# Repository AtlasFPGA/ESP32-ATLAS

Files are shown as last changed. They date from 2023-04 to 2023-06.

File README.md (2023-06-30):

# ESP32-ATLAS
   Diseño en desarrollo para el ESP32 DEV KIT V1 usado de forma básica con sus  25 señales,se necesita disponer de un VGA64.
   No podíamos dejar pasar la oportunidad de alojar el ESP32 en el interior de la I/O BOARD ATLAS,este microcontroladro lleva muchos años en el mercado,tant es así que el ESP32 sigue siendo un producto puntero.
   Es importantísimo tener su Software en ATLAS, y con la tercera iteración de correspondencia de pines cubre toda la placa I/O BOARD ATLAS.
   La inicialización de FABGL con su configuración en la mayoría de las placas es la siguiente.
inicialización VGA FABGL:

   Vídeo que muestra, el correcto funcionamiento del recolocador que nos permitirá jugar con audio amplificado, i2s así como i2c en el futuro.

---

## Correcto funcionamiento recolocador ESP32:

Correcto funcionamiento del recolocador ESP32 (https://youtu.be/WPQtUhWn7BE)

---

VGAController.begin(GPIO_NUM_22, GPIO_NUM_21, GPIO_NUM_19, GPIO_NUM_18, GPIO_NUM_5, GPIO_NUM_4, GPIO_NUM_23, GPIO_NUM_15);

Leyendo el quema vemos que significado tiene de señales con sus nombres lógicos de los bits de color así como la frecuencia horizontal y vertical.

VGAController.begin(RED_1, RED_0 , GREEN_1, GREEN_0, BLUE_1, BLUE_0, H_SYNC, V_SYNC)

Inicialización ESP32 en ATLAS con el recolocador creado:

## VGAController.begin(GPIO_NUM_32, GPIO_NUM_33, GPIO_NUM_27, GPIO_NUM_4, GPIO_NUM_17, GPIO_NUM_13, GPIO_NUM_16, GPIO_NUM_15);

El recolocador de ATLAS tiene una colocación diferente.
---

Colocación del ESP32 en la placa I/O Board ATLAS Morada:
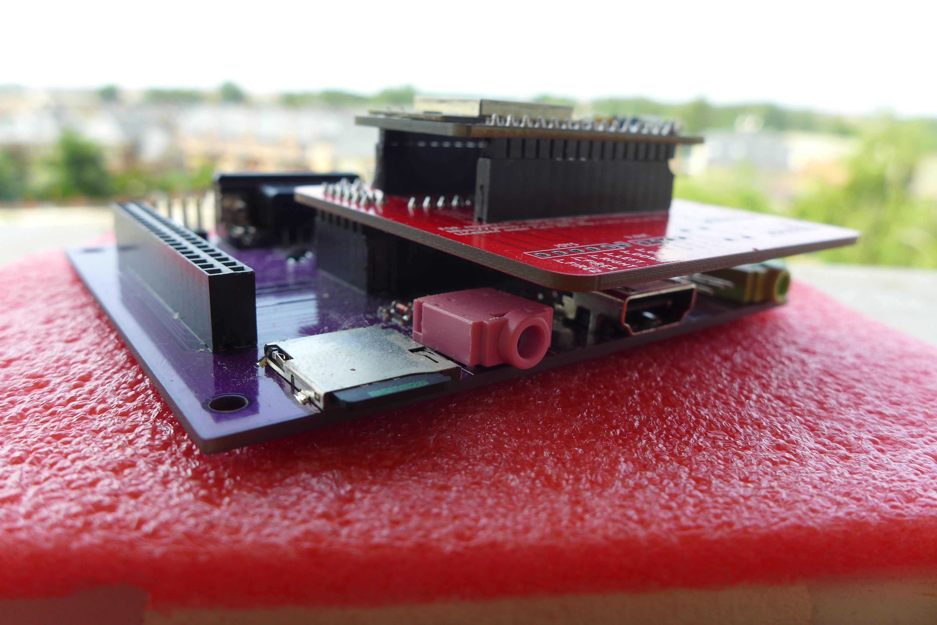
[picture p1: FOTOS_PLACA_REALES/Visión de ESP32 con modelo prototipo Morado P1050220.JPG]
Colocación del ESP32 en la placa I/O Board ATLAS Morada


---

Placa "La Roja" vista con el recolocador ESP32 desde el bus del sbc:
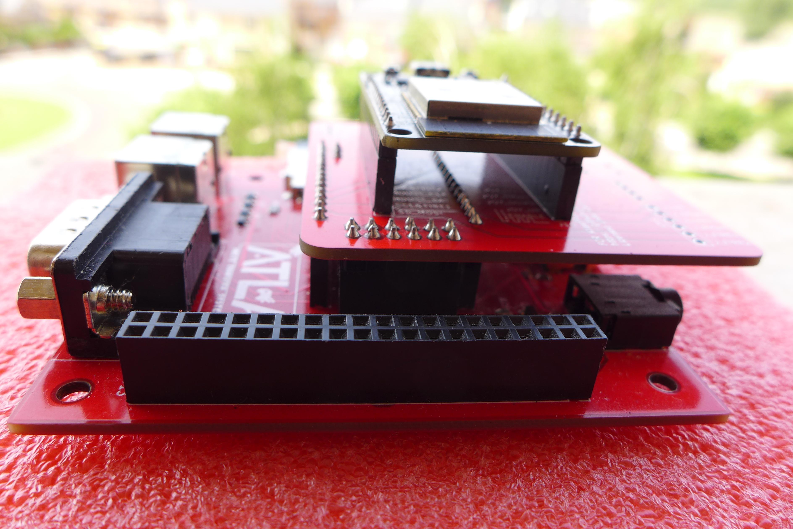
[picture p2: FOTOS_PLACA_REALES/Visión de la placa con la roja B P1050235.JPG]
Placa "La Roja" vista con el recolocador ESP32 desde el bus del sbc


---

Ensamblado ESP32 visto desde los puertos ps2 y db9 norma atari:
Ensamblado ESP32 visto desde los puertos ps2 y db9 norma atari

---

Visión de la placa recolocadora ESP32 superior:
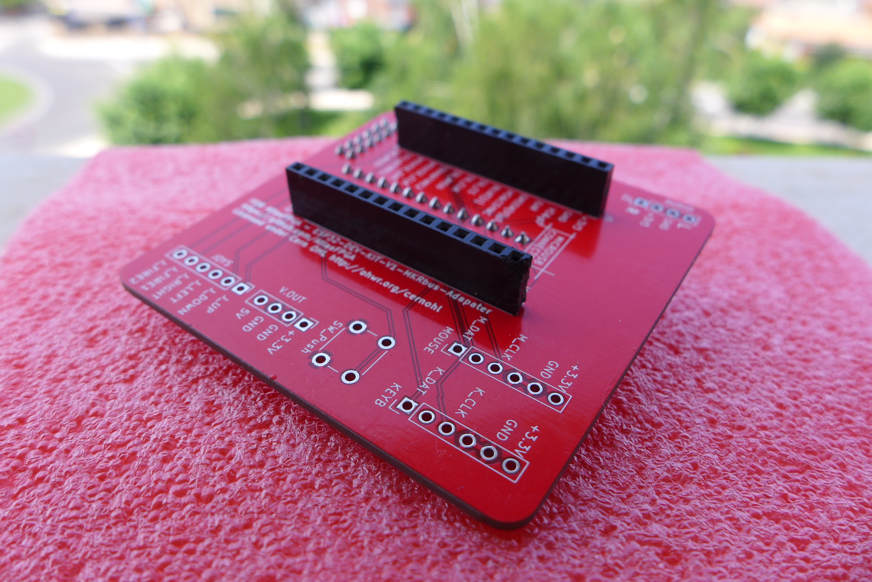
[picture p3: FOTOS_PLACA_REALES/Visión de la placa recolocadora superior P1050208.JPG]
Visión de la placa recolocadora superior


---
Visión de la placa recolocadora ESP32 infernior:
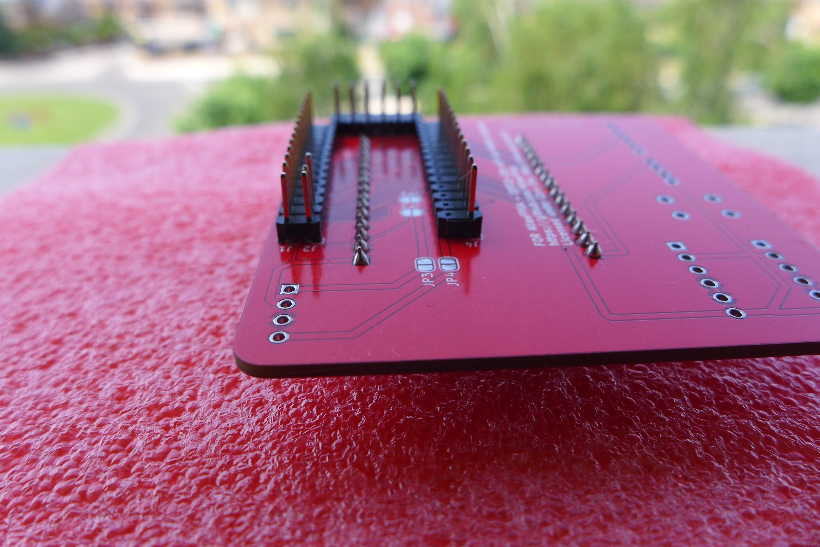
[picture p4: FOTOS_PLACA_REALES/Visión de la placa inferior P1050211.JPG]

   
---   

# Versión final sin amplificación de sonido:

Ver vídeo diseño recolocador (https://www.youtube.com/watch?v=FslLuDT2TB8)

---   

# Vídeo del proceso de desarrollo del recolocador para ESP32 DEV KIT V1; así como mostrar el funcionamiento del VGA64 222+HS+VS de la placa I/O Board ATLAS:

Ver vídeo primera iteracion bitluni (https://www.youtube.com/watch?v=wdI3RePPbeQ)
  
---

señales ATLAS| aclaración en ESP32 DEV KIT 1 | numero pines
| :--- | ---: | :---:
Señal VGA64 | Casi todos los cores de ESP32 usan 64colores esquema 222+HS+VS | 8
Señal JOYSTICK DB9 | En preparación ATARI-PADDLE-ATLAS  | 6
Señal SD SPI | las señales QPI se usan en modo SPI| 4
Señal PS2 TECLADO  | Protocolo PS/2 | 2
Señal PS2 RATÓN | Protocolo PS/2 | 2
Señal Sonido Estereo | sonido delta sigma_(12bits) o un pwm_(10bits), DAC_ESP32(8bits)| 2
Señal Transmisión y Recepcion | RX TX sin gestión de flujo| 2
Señal EAR | Señal de entrada | 1

   No hay lugar para Las Señales de RX y TX como GPIOS, se tendrá que acceder desde el USB.
   En este diseño son Necesarias 27 señales, pero el ESP32 DEV KIT V1 dispone de 25 patillas/señales de las cuales 4 son de entrada, ahí conectamos las direcciones del mando de juegos de norma ATARI en el bus DB9.

   Inicialmente antes de realizar el recolocador final,hemos usado el esquema de bitluni:
   
   http://www.fabglib.org/conf_v_g_a.html
   
   Con la siguiente disposición de pines para la primera iteración de pines:
   
   VGAController.begin(GPIO_NUM_22, GPIO_NUM_21, GPIO_NUM_19, GPIO_NUM_18, GPIO_NUM_5, GPIO_NUM_4, GPIO_NUM_23, GPIO_NUM_15);
   
PINEADO


##   Nota importante fijarse en los 4 pines que sólo permiten señales de entrada corresponden a los GPIO36, GPIO39, GPIO34, y GPIO35.

---

# ASIGNACIÓN ACTUAL; buscando tener el I2C con pull up en el DB9 y los 2 DAC de 8bits de resolución en la salida de sonido:
   los GPIO asociados a la salida de los dac de 8bit cada uno son, el GPIO25 y GPIO26.
   Esta es tercera iteración en su configuración final para el recolocador, a nivel lógico, sin amplificación de la señal de audio, para habilitar el puerto de audio con tensiones, es necesario cortar 2 pad stereo para que no llegue la señal a la I/O BOARD ATLAS, y estañar los pads que llevan las señales ESP_AUDIO_8BIT, al conector con tensión 3v3 y GND.

señales ATLAS | Patillaje izquierda | patilaje derecha | señales ATLAS
| ---: | ---: | ---: | :---: 
ENABLE| ENABLE | GPIO23| T14_SD_MOSI
J14_JOY_UP| GPIO36 | GPIO22| K15_JOY_FIRE1
R1_JOY_DOWN| GPIO39 | GPIO01 | MOUSE_DAT
N16_JOY_RIGHT| GPIO34 | GPIO03 | MOUSE_CLK
T15_JOY_LEFT| GPIO35 | GPIO21| K16_JOY_FIRE2
TMDS_2_P| GPIO32 | GPIO19 | R13_SD_MISO
TMDS_2_N| GPIO33 | GPIO18 | T13_SD_CLK
R11_RIGHT| GPIO25 | GPIO05 | R12_SD_CS
T12_LEFT| GPIO26 |GPIO17 | TMDS_O_P
TMDS_1_P| GPIO27 | GPIO16 | TMDSC_N
ATLAS Mini -> L2_KCLK,Morada -> K2_KDAT| GPIO14 | GPIO04 | TMDS_1_N
ATLAS Mini -> K2_KDAT,Morada -> L2_KCLK| GPIO12 | GPIO02 | EAR
TMDS_0_N| GPIO13 | GPIO15 | TMDSC_P
GND| GND | GND| GND
+5V| VIN | +3V3| +3V3

---
# TABLA EQUIVALENCIAS SALIDA CONECTOR DE VÍDEO DIGITAL
Nomenclatura DVI | Pares diferenciales | VGA64 | SCART128 | ZX-SCART
| ---: | ---: | ---: | ---: |:---: 
TMDS[0]|CLK- | HS | CSYNC | CSYNC
TMDS[1]|CLK+ | VS | G[0]  | BRIGHT
TMDS[2]|0-   | BLUE[0] | BLUE[0] | I2S_DIN_SD 
TMDS[3]|0+   | BLUE[1] | BLUE[1] | B
TMDS[4]|1-   | GREEN[0] | G[1] | I2S_BCLK_SCK
TMDS[5]|1+   | GREEN[1] | G[2] | G
TMDS[6]|2-   | RED[0] | RED[0] | I2S_LRC_WS
TMDS[7]|2+   | RED[1] | RED[1] | R

Las señales por determinar del módulo ZX-SCART llevan al menos en serie una resistencia de 270 ohm, pero al ser 3 señales se puede luchar icorporar al DAC de 15 colores un I2S, se han reflejado tanto la terminología de DAC como Micrófono por I2S.

Nota: en modo DVI y anulando los pares diferenciales negativos es decir a 0V, una señal de baja resolución tendría que generar los datos para los 3 colores en digital, y un reloj constate y 5 veces más veloz que el reloj de pixel asociado a su misma resolucion en analógico, en total 4 señales de vídeo digital, no sabemos si estas señales DVI pueden ser generadas.

---

   Esquema de referencia usado al inicio de las iteraciones:
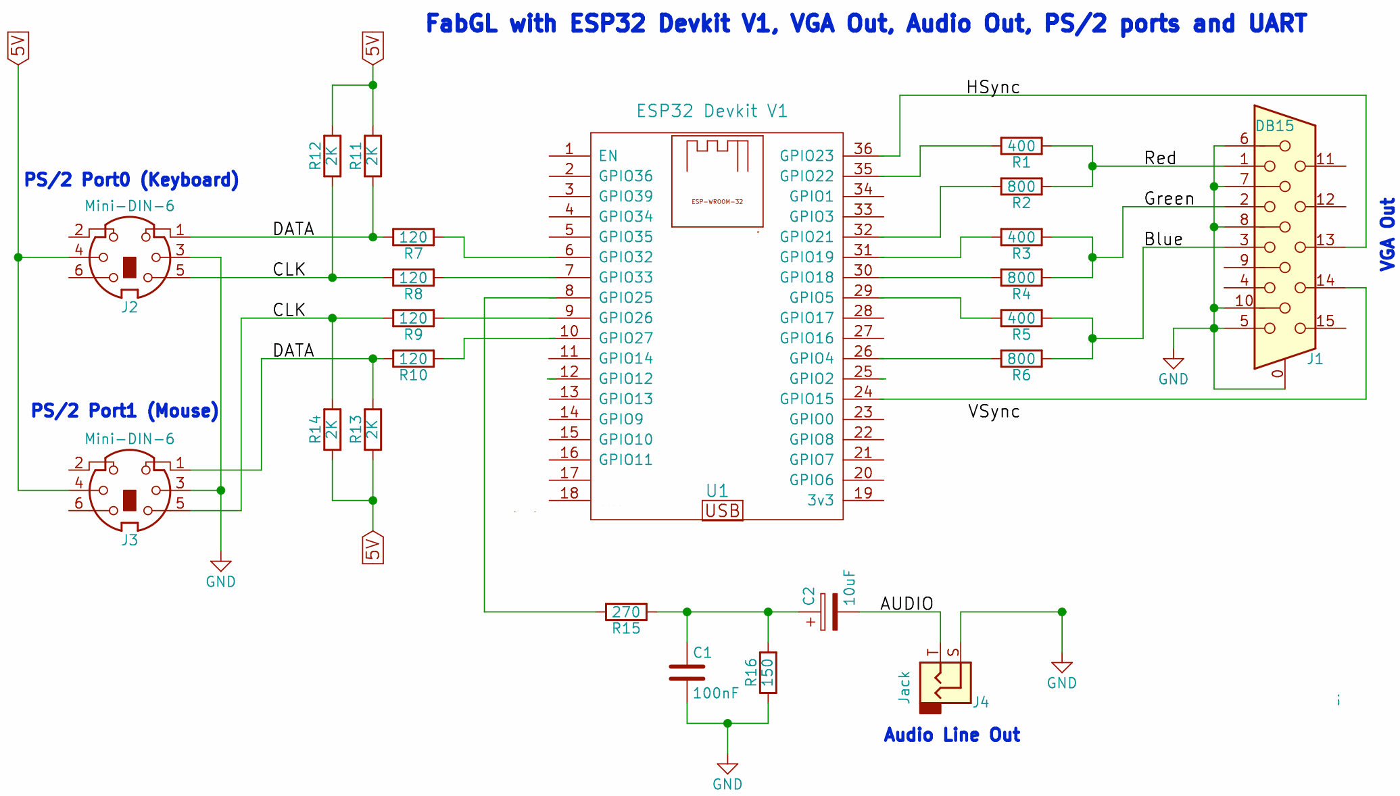
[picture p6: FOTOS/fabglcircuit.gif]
Esquemático de referencia FABGL

    
---

   Lo que hace un total de 25 pines GPIO, para aumentar el diseño, esta el DB9 con 6 pines en PULL UP (Consultar esquema ATLAS-MINI), permite ampliarse el modelo existente mediante integrados I2C, con un buses de entrada salida en el bus DB9, tener en cuenta de las otras 4 señales, obligatoriamente tiene que ser señales de entrada.
   
   Consulta del esquema ATLAS MINI "La Roja" con licencia CERN OHL V2 STRICT:
   
   https://github.com/AtlasFPGA/BASECARRIERBOARDATLAS
   
   Consulta del esquema en easyeda:
   
   https://oshwlab.com/subcritical/carrier_io_board_atlas_mini_copy
   
## Dimensiones:

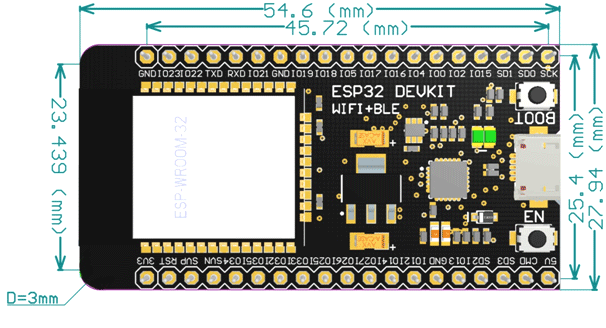
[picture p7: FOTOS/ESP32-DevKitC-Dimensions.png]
ESP32-DOIT-DEVKIT-V1


## Las características del Esp32:

Los lenguajes de programación más usados para NodeMCU ESP32, son Arduino y MicroPython. Ambos son de código abierto y cuentan con herramientas de desarrollo gratuitas.
 
## Especificaciones:

• Placa: ESP32 DEVKIT V1 (Espressif)

• SoM (System on module): ESP-WROOM-32 (Espressif)

• SoC (System on chip): ESP32 (ESP32-D0WDQ6)

• Procesador: Tensilica Xtensa Dual-Core 32-bit LX6.

• Frecuencia del reloj: 160 a 240 Mhz.

• Desempeño: Hasta 600 DMIPS

• Memoria:

448 KByte ROM

520 KByte SRAM

16 KByte SRAM in RTC (Real Time Clock)

QSPI Flash/SRAM, 4 MBytes

• Número total de pines GPIO: 25

• WiFi con antena integrada: estándar 802.11 b/g/n. Velocidad de 150.0 Mbps

• Bluetooth: BLE (Bluetooth Low Energy) y Bluetooth Classic

• Interfaz USB-Serial CP2102 on board.

• Modo de funcionamiento Low Power.

• Peripheral Input/Output (25 pines GPIO)

• ADCs (Convertidores Analógico Digital) de 12 bits

• DACs (Convertidores Digital Analógico) de 8 bits

• I²C (Inter-Integrated Circuit)

• UART (Universal Asynchronous Receiver/Transmitter)

• SPI (Serial Peripheral Interface)

• I²S (Integrated Interchip Sound)

• RMII (Reduced Media-Independent Interface)

• PWM (Pulse-Width Modulation).

• Regulador de 3.3 volts on board.

• Voltaje de Alimentación (conector MicroUSB): 5v, 0.5A

• Niveles de voltaje de entradas/salidas: 3.3v

• Corriente máxima en salidas: IOH=40ma (source), IOL=28ma (sink).

- Dimensiones: 51.5 mm x 28.3 mm x 12 mm

- Distancia entre pines: estándar 2.54 mm

- Distancia entre ambas filas de pines: 26.0 mm

- Número total de pines: 30

   Fuente de características y mapeado de pines del microcontrolador de Espressif ESP32.

https://www.puntoflotante.net/NODEMCU-ESP32-DEVKIT-V1-STARTER-KIT.htm

##   En total ATLAS pone a dispocisión con el recolocador ESP32-ATLAS unas 25 señales, completando todas las señales que le puede brindar la I/O BOARD ATLAS: 

Si   hubiera una linea a mayores disponible sería muy interesante que actuara automáticamente un CS_PADDLE sobre el ATARI-PADDLE-ATLAS.

---

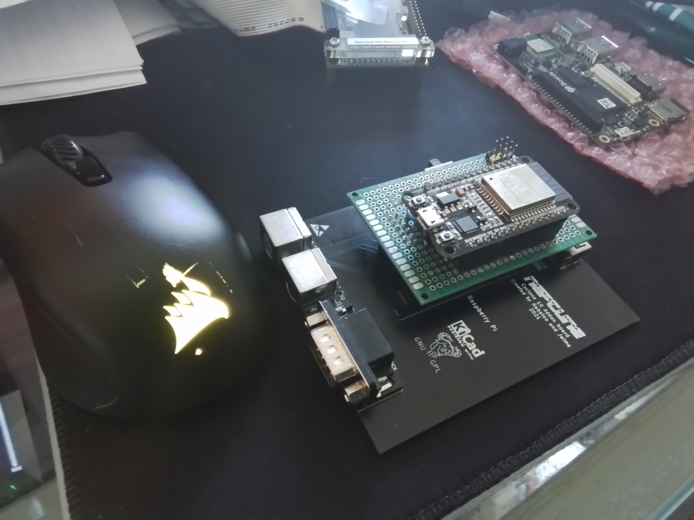
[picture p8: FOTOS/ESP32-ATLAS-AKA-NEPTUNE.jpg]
ESP32-ATLAS-AKA-NEPTUNE


---

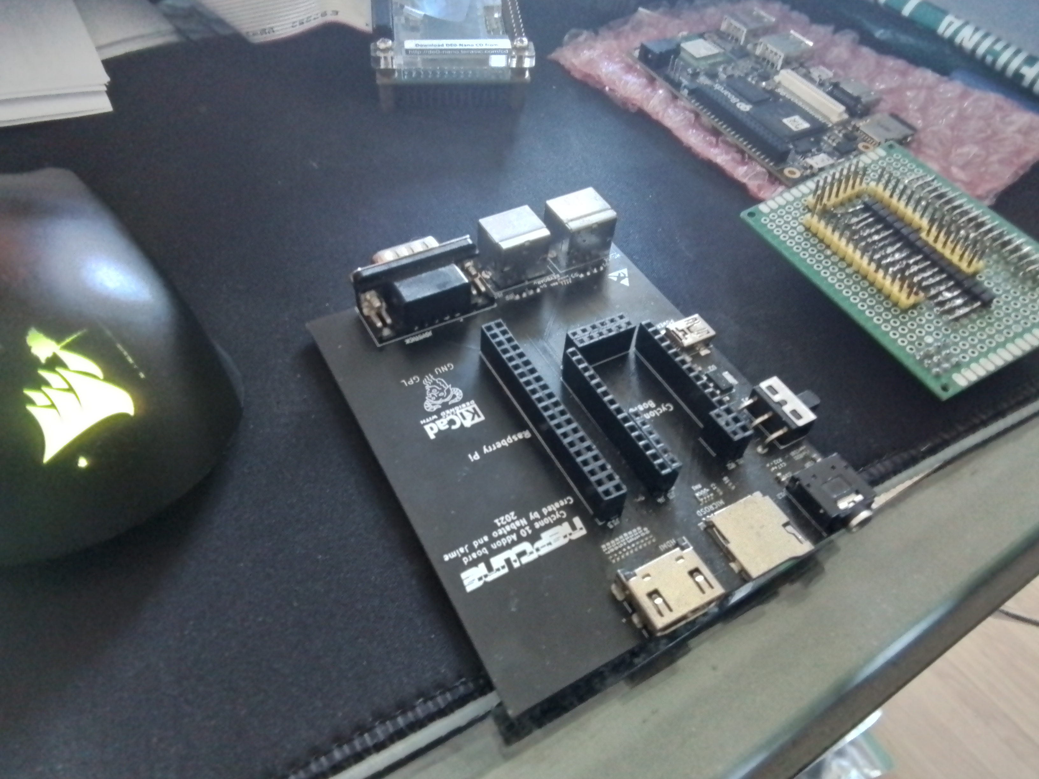
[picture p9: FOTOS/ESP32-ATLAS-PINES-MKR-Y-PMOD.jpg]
ESP32-ATLAS-PINES-MKR-Y-PMOD


---

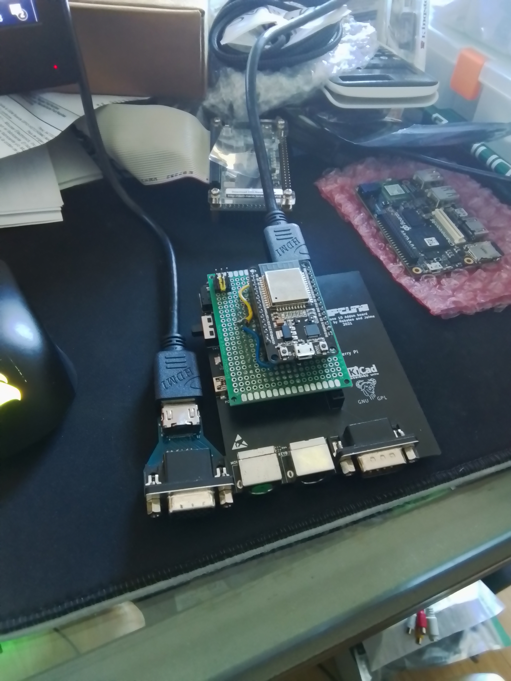
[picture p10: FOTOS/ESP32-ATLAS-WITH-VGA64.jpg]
ESP32-ATLAS-WITH-VGA64


---

VERIFICACIÓN FUNCIONAMIENTO

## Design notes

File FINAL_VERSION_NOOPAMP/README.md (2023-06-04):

# ESP32-DEVKIT-V1-Fpga-Relocator
PCB for plug a ESP32 DEV KIT V1 on MKR bus for use Atlas resources

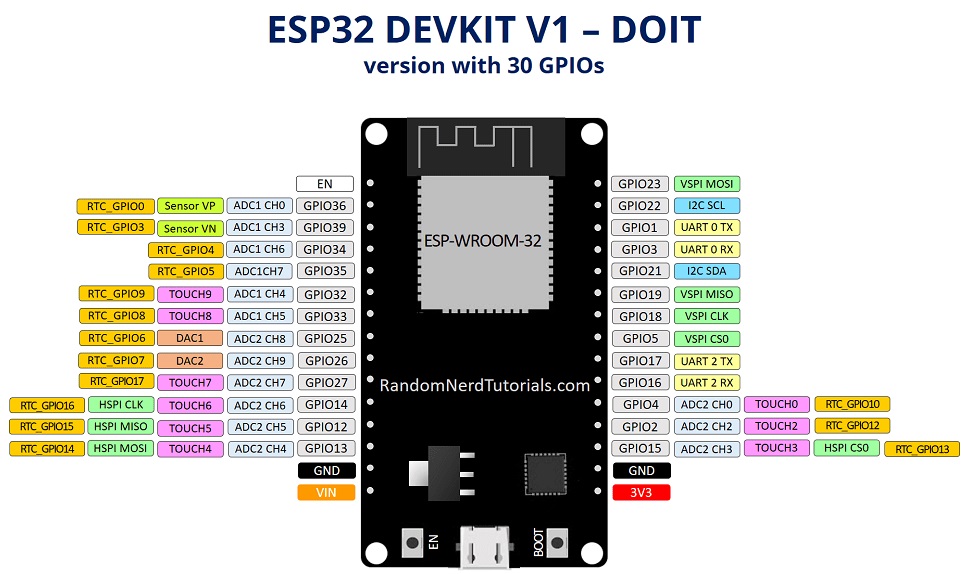
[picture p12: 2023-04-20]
FOTOS/ESP32-DOIT-DEVKIT-V1-Board-Pinout-30-GPIOs-2.jpg

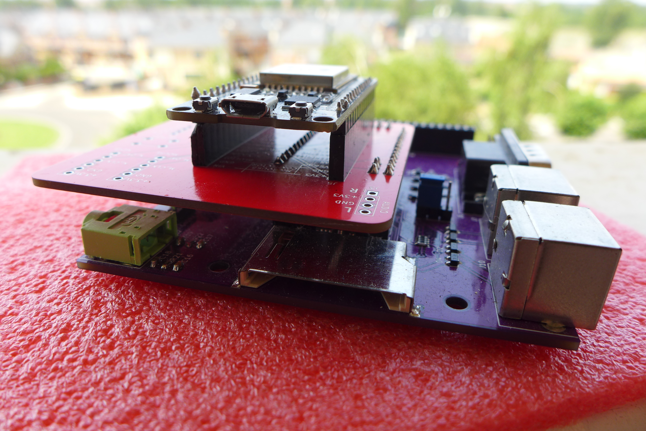
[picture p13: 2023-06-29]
FOTOS_PLACA_REALES/Visión de la placa recolocadora esp32 con prototipo morado P1050222.JPG

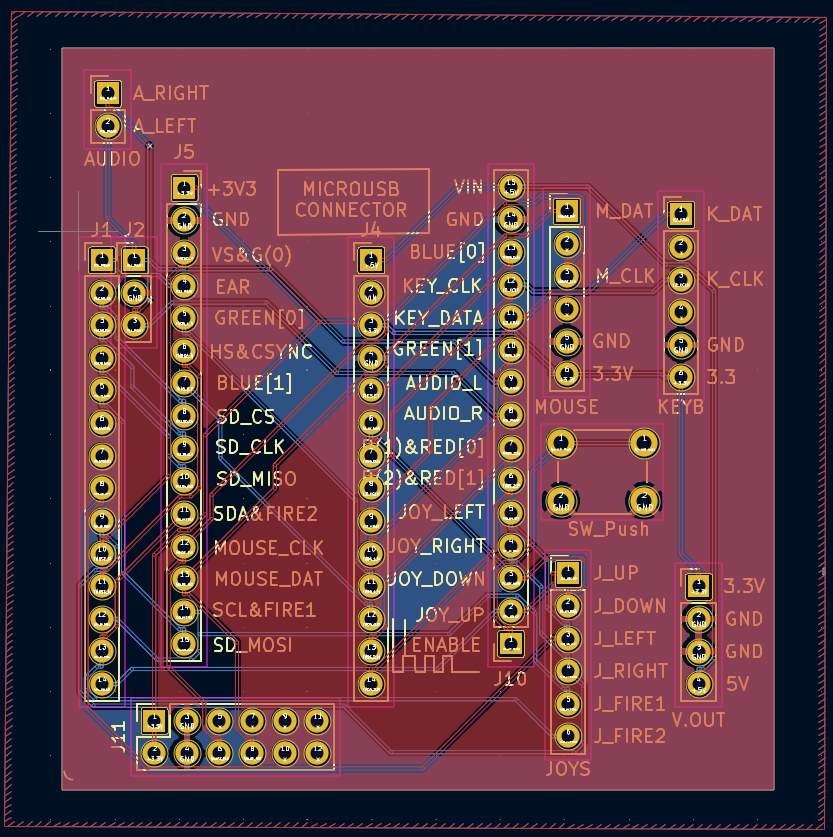
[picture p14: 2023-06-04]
FOTOS/Recolocador_ESP32-Dev-kit-v1-0010.png

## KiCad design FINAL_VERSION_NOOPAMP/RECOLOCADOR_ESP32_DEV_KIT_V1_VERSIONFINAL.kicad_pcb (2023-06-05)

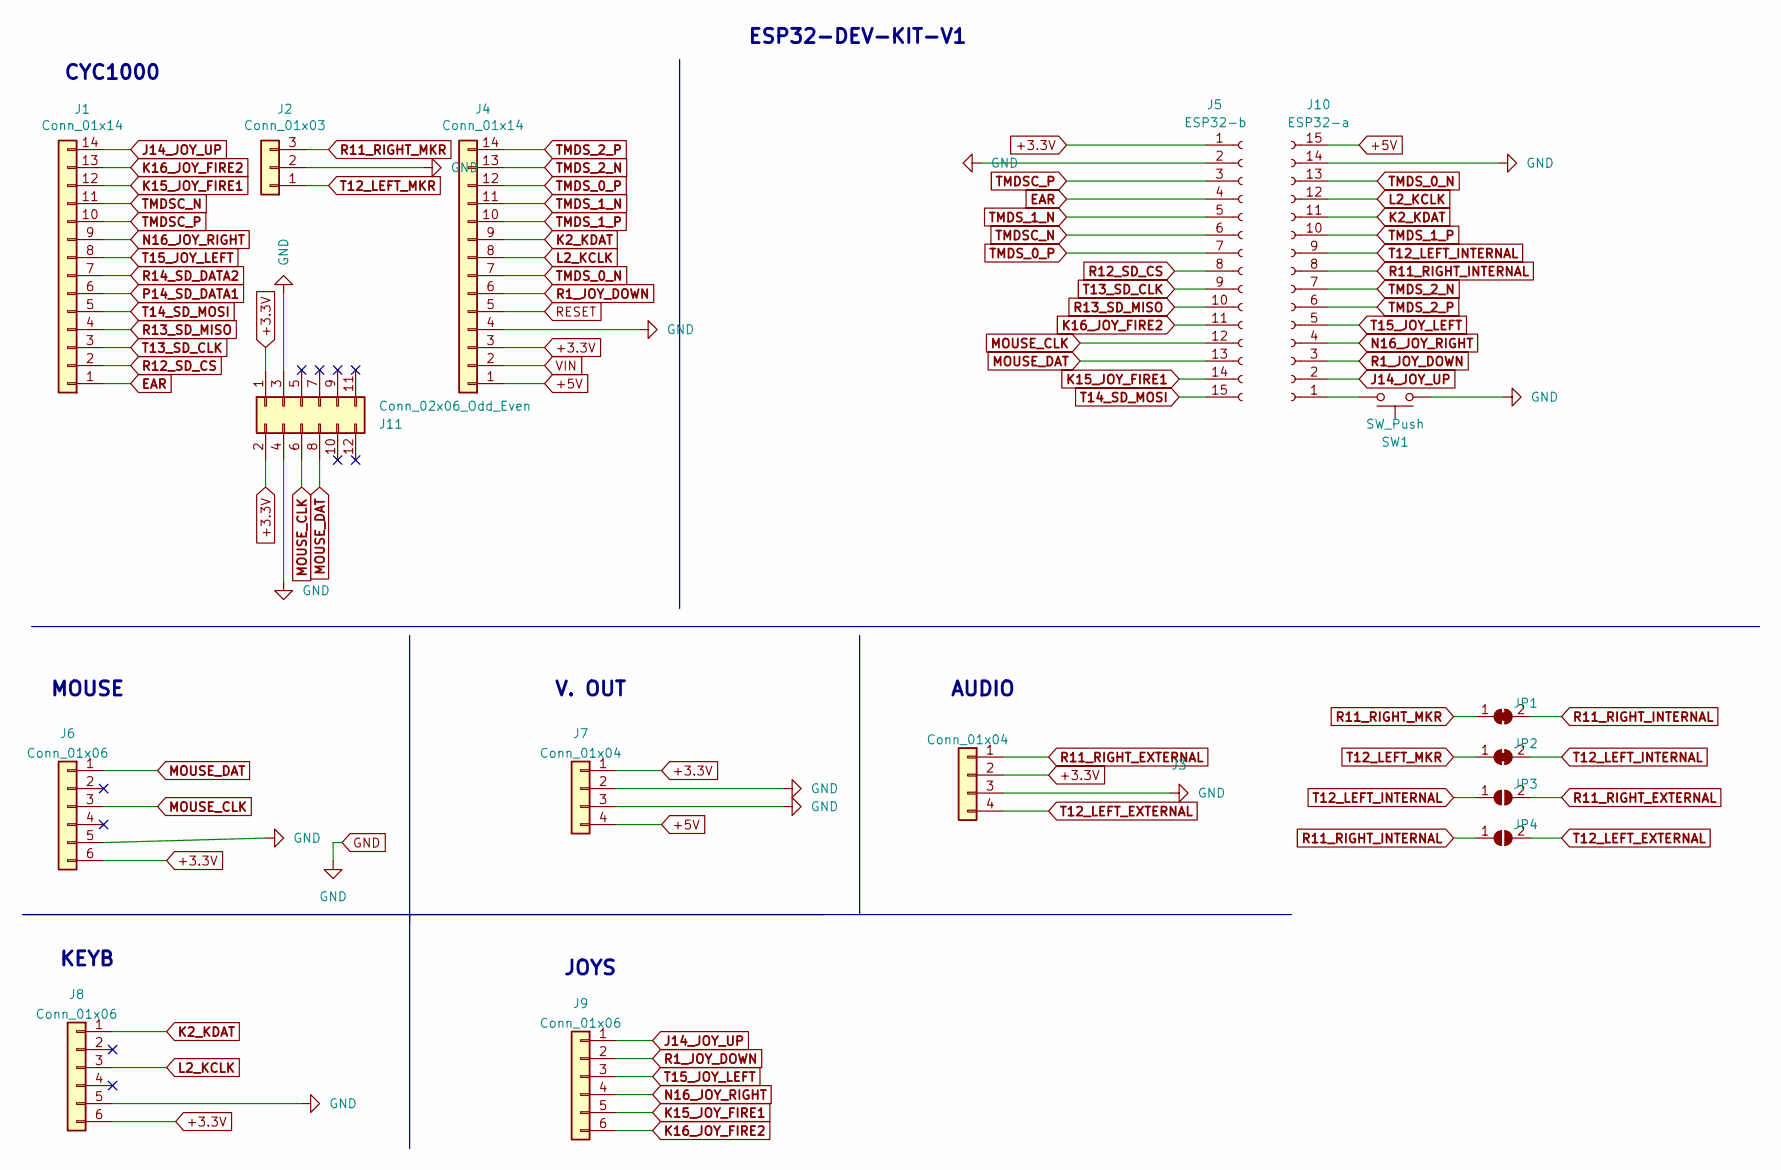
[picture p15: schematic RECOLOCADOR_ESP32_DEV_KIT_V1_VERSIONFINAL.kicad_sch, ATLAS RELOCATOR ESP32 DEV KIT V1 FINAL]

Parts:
J1, J4: Conn_01x14; PinHeader_1x14_P2.54mm_Vertical
J2: Conn_01x03; PinHeader_1x03_P2.54mm_Vertical
J3, J7: Conn_01x04; PinHeader_1x04_P2.54mm_Vertical
J5: ESP32-b; PinSocket_1x15_P2.54mm_Vertical
J6, J8, J9: Conn_01x06; PinHeader_1x06_P2.54mm_Vertical
J10: ESP32-a; PinSocket_1x15_P2.54mm_Vertical
J11: Conn_02x06_Odd_Even; PinHeader_2x06_P2.54mm_Vertical
JP1, JP2: SolderJumper_2_Bridged; SolderJumper-2_P1.3mm_Bridged2Bar_RoundedPad1.0x1.5mm
JP3, JP4: SolderJumper_2_Open; SolderJumper-2_P1.3mm_Open_RoundedPad1.0x1.5mm
SW1: SW_Push; SW_PUSH_6mm

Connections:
+3.3V: J3.2, J4.3, J5.1, J6.6, J7.1, J8.6, J11.1, J11.2
+5V: J4.1, J7.4, J10.15
EAR: J1.1, J5.4
GND: J2.2, J3.3, J4.4, J5.2, J6.5, J7.2, J7.3, J8.5, J10.14, J11.3, J11.4, SW1.2
J14_JOY_UP: J1.14, J9.1, J10.2
K2_KDAT: J4.9, J8.1, J10.11
K15_JOY_FIRE1: J1.12, J5.14, J9.5
K16_JOY_FIRE2: J1.13, J5.11, J9.6
L2_KCLK: J4.8, J8.3, J10.12
MOUSE_CLK: J5.12, J6.3, J11.6
MOUSE_DAT: J5.13, J6.1, J11.8
N16_JOY_RIGHT: J1.9, J9.4, J10.4
unnamed: J10.1, SW1.1
P14_SD_DATA1: J1.6
R1_JOY_DOWN: J4.6, J9.2, J10.3
R11_RIGHT_EXTERNAL: J3.1, JP3.2 (B)
R11_RIGHT_INTERNAL: J10.8, JP1.2 (B), JP4.1 (A)
R11_RIGHT_MKR: J2.3, JP1.1 (A)
R12_SD_CS: J1.2, J5.8
R13_SD_MISO: J1.4, J5.10
R14_SD_DATA2: J1.7
RESET: J4.5
T12_LEFT_EXTERNAL: J3.4, JP4.2 (B)
T12_LEFT_INTERNAL: J10.9, JP2.2 (B), JP3.1 (A)
T12_LEFT_MKR: J2.1, JP2.1 (A)
T13_SD_CLK: J1.3, J5.9
T14_SD_MOSI: J1.5, J5.15
T15_JOY_LEFT: J1.8, J9.3, J10.5
TMDSC_N: J1.11, J5.6
TMDSC_P: J1.10, J5.3
TMDS_0_N: J4.7, J10.13
TMDS_0_P: J4.12, J5.7
TMDS_1_N: J4.11, J5.5
TMDS_1_P: J4.10, J10.10
TMDS_2_N: J4.13, J10.7
TMDS_2_P: J4.14, J10.6
VIN: J4.2

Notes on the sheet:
MOUSE
CYC1000
AUDIO
KEYB
JOYS
ESP32-DEV-KIT-V1
V. OUT

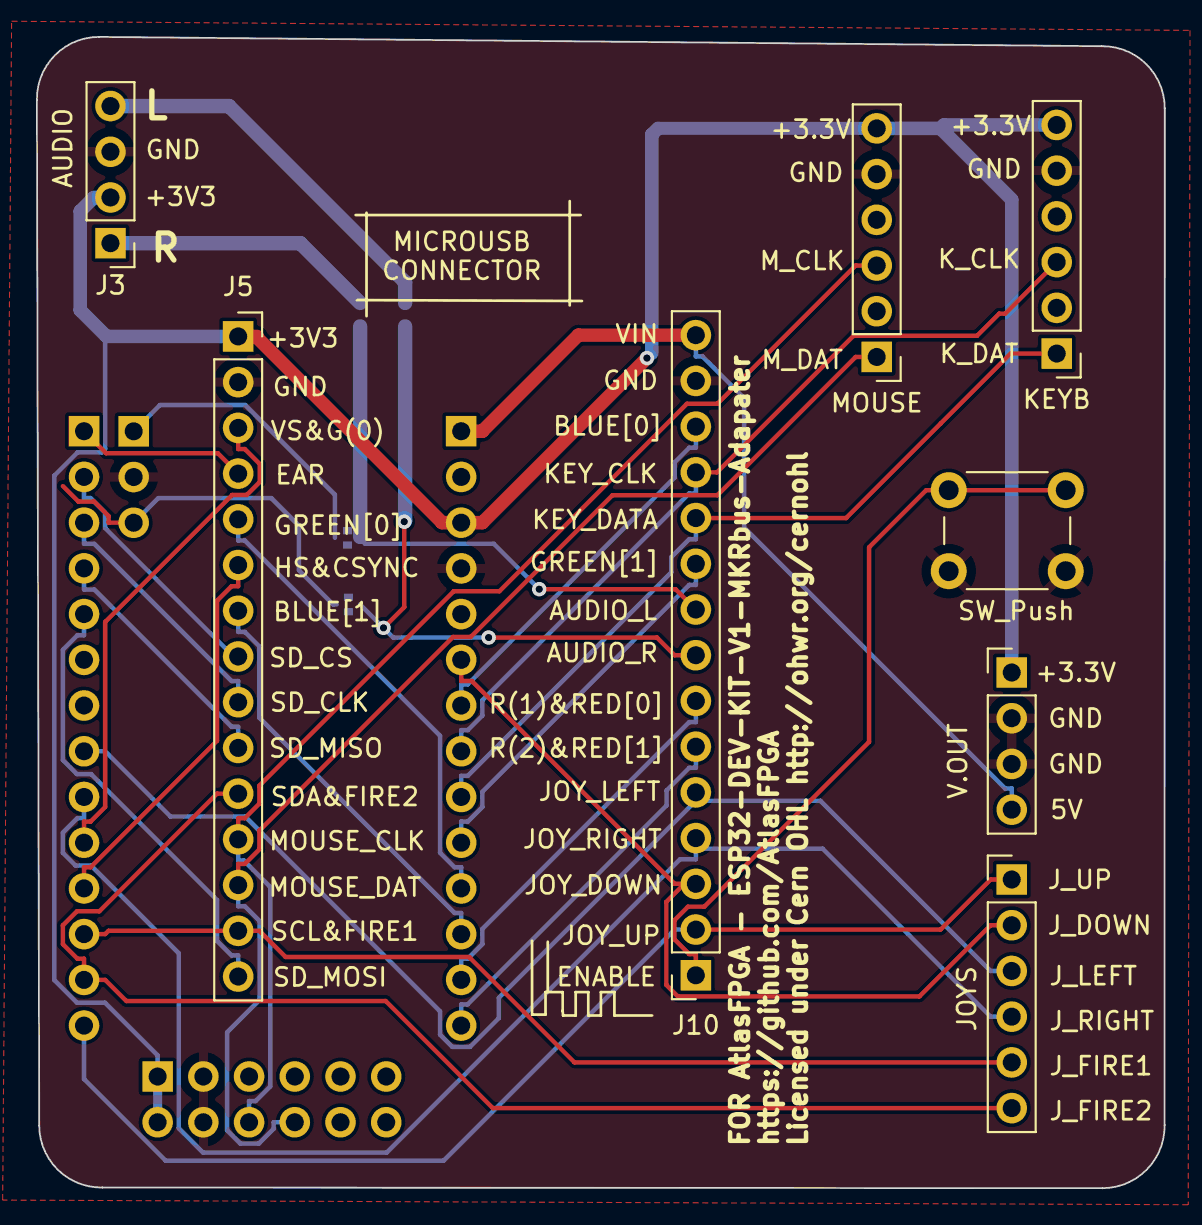
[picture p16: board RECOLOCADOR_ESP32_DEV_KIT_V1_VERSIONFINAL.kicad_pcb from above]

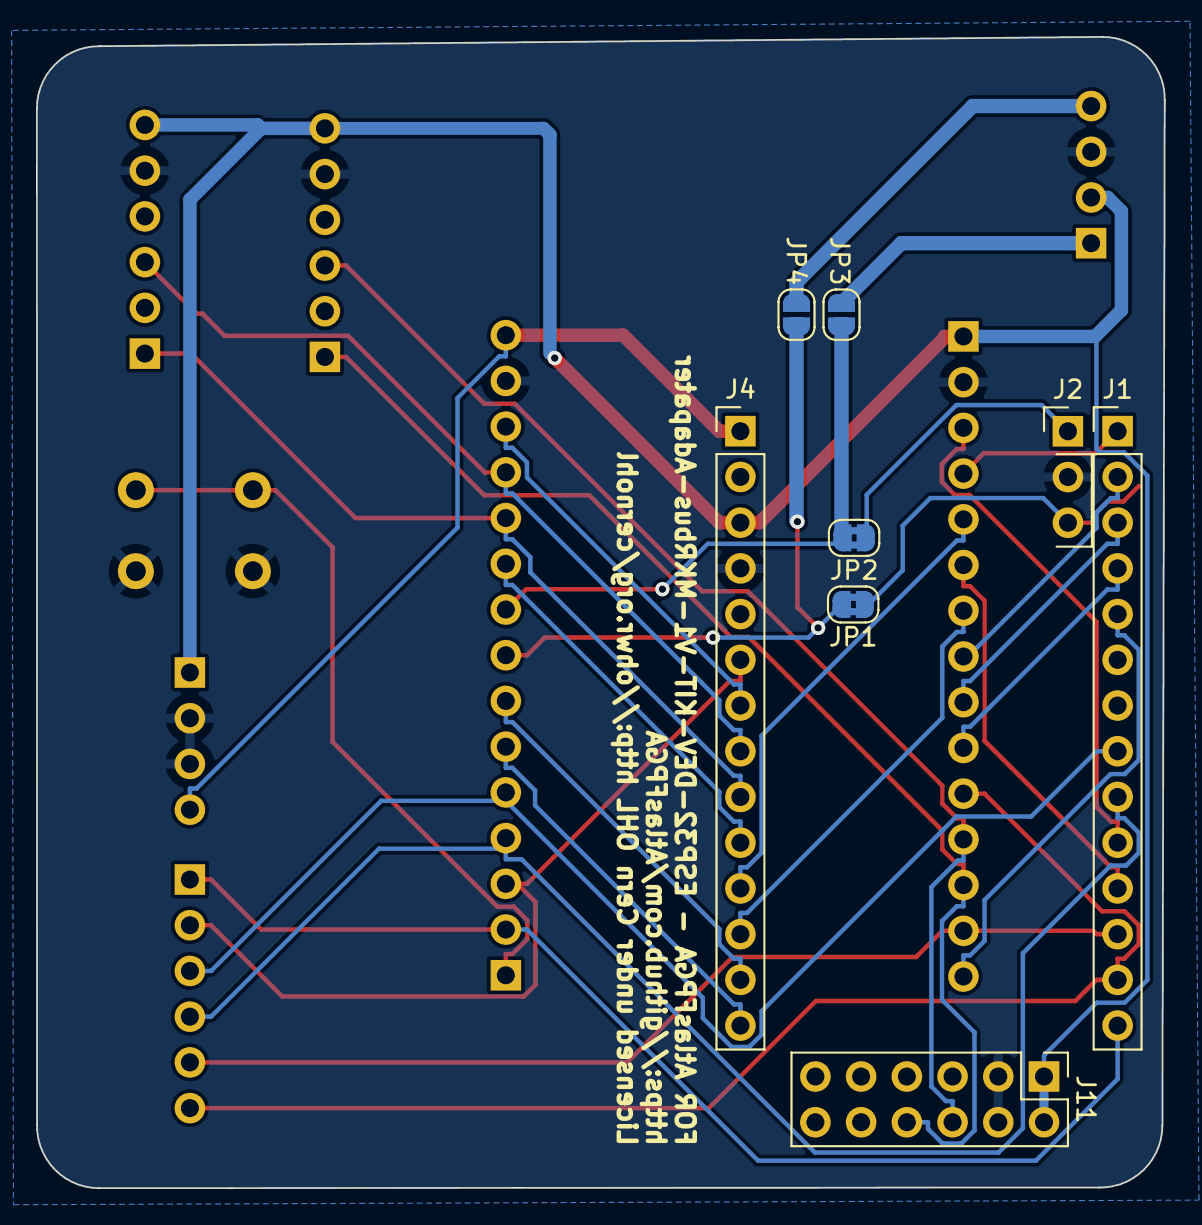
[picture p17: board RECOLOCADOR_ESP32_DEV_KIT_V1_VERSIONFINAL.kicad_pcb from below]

Board: 2 copper layers, 62.7 x 64.0 mm, 16 parts (8 on the bottom side), 33 nets.

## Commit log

2023-04-20 Subida de imágenes protipo ESP32-ATLAS.
    Esta vez como hay muchos modelos de ESP32, así como pineados para la VGA222, He optado por una forma clásica de afrontar el problema creando primero un modelo real.
    Se fija el modelo más económico de ESP32 y el más accesibles desde hace casi 8 años, el ESP32 DEV KIT V1.
2023-04-20 Crear un readme con las imágenes iniciales de ESP32-ATLAS
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2023-04-20 Pineado ESP32
    Pineado para la versión ESP32 DEV KIT V1, la más usada de todas las versiones de ESP32.
2023-04-20 Añadido Los señales del microcontrolador ESP32 DEV KIT V1
2023-04-20 Agregar características ESP32 DEV KIT V1
2023-04-20 Mejoras en la información relativa al ESP32.
2023-04-20 Información del desarrollo del ESP32-ATLAS
2023-04-20 Añadidas las señales RX y TX sin control de flujo.
2023-04-20 Actualización información ESP32 DEV KIT V1
2023-04-20 Actualizar información ESP32 DEV KIT V1
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2023-04-20 Actualizaciones de información sobre el bus multipropósito DB9.
2023-04-20 Añadidas las direcciones de easyeda y kicad de I/O BOARD ATLAS MINI
2023-04-20 Actualización de direcciones easyeda I/O BOARD ATLAS MINI
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2023-04-21 Añadidas correspondencias señales ESP32 con I/O Board ATLAS
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2023-04-21 Añadir paletas de colores y pineado del ESP32 DEV KIT V1
2023-04-21 Tabla de correspondencias I/O Board ATLAS y ESP32
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2023-06-02 Verificación funcionamiento con una placa de prototipo ESP32 en VGA64 con I/O BOARD ATLAS
2023-06-02 ESP32 DEV KIT V1 con la configuración FABGL en I/O BOARD ATLAS
2023-06-04 Nueva asignación final con todos los pines en uso, disponible spi, así como i2c en el puerto DB9.
2023-06-04 Aclaración del modelo kicad de ESP32 KIT V1, copando todos los puertos de la placa I/O Board ATLAS.
2023-06-04 Diseño de recolocador ESP32 DEV KIT V1, usando la misma terminología de recolocador de @Shaeon
    [Atlas_ESP32_DEV_KIT_V1_001.dsn, Atlas_ESP32_DEV_KIT_V1_001.kicad_pcb, Atlas_ESP32_DEV_KIT_V1_001.kicad_sch]
2023-06-04 Diseño de recolocador ESP32 DEV KIT V1, usando la misma terminología
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2023-06-04 Proceso de diseño en desarrollo de un recolocador para el ESP32 DEV KIT V1
2023-06-04 Creación carpeta con placa BETA ESP32 DEV KIT V1
2023-06-04 Diseño BETA considerado final sin amplificador de sonido.
    [Atlas_ESP32_DEV_KIT_V1_001.dsn, Atlas_ESP32_DEV_KIT_V1_001.kicad_pcb, Atlas_ESP32_DEV_KIT_V1_001.kicad_sch]
2023-06-04 Versión Beta del recolocador sin amplificación de sonido
2023-06-04 Agregado la versión final sin amplificación de sonido.
2023-06-04 Agregar foto del modelo de recolocador final para placa sin amplificación de sonido
2023-06-04 Update and rename README.md to Agregar información sobre la tabla de correspondencias del VGA64
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2023-06-04 Actualización del recolocador ESP32 DEV KIT V1 que se muestra en el vídeo.
    Recolocador ESP32 DEV KIT V1:
    https://www.youtube.com/watch?v=cKaD_CqJWqs
    [Atlas_ESP32_DEV_KIT_V1_Version0010.dsn, Atlas_ESP32_DEV_KIT_V1_Version0010.kicad_pcb, Atlas_ESP32_DEV_KIT_V1_Version0010.kicad_sch]
2023-06-04 Actualizada información del recolocador para ESP32 DEV KIT V1 VIDEO
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2023-06-04 Añadida información de recolocador ESP32 DEV KIT V1
2023-06-05 Placa RECOLOCADOR ESP32 DEV KIT V1
    Modelo v0011 del recolocador para ESP32 DEV KIT V1, verificada la posición de las señales, el poder disponer de esp32 intercambiables al usar el dev kit v1 permite su reemplazo, la placa escogida es 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
    Hay que tener en cuenta que se han cambiado todas las señales, y no corresponden con FABGL, dado que se busca poder disponer del I2C en el DB9 en las señales de disparo, y cumplir el requisito de 4 s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
    En cuanto a la señal DVI, no sabemos si se podrá conseguir generar una señal DVI de baja resolución, pero el funcionamiento del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
    [Atlas_ESP32_DEV_KIT_V1_Version0011.dsn, Atlas_ESP32_DEV_KIT_V1_Version0011.kicad_pcb, Atlas_ESP32_DEV_KIT_V1_Version0011.kicad_sch]
2023-06-05 Asignadas las señales para el I2S del ZX-SCART
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2023-06-05 VERSION FINAL NO_OP_AMP
    [Atlas_ESP32_DEV_KIT_V1_Version0100.dsn, RECOLOCADOR_ESP32_DEV_KIT_V1_VERSIONFINAL.dsn, RECOLOCADOR_ESP32_DEV_KIT_V1_VERSIONFINAL.kicad_pcb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]
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2023-06-06 Subida de gerbers último modelo de recolocador para ESP32 DEV KIT V1
    [RECOLOCADOR_ESP32_DEV_KIT_V1_VERSIONFINAL-B_Cu.gbl, RECOLOCADOR_ESP32_DEV_KIT_V1_VERSIONFINAL-B_Mask.gbs, RECOLOCADOR_ESP32_DEV_KIT_V1_VERSIONFINAL-B_Paste.gbp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]
2023-06-07 Agregada información en la discrepancia de teclado
    La configuración del ultimo prototipo "LA MORADA" sufrió una inversión de pines en las lienas de datos y reloj asociados al ps2.
    Se ha indicado esta discrepancia en la correspondencia de pines del recolocador.
2023-06-29 Se agregan las fotos de como queda la placa ESP32 para I/O Board ATLAS, en su versión MINI-> La Roja, y el último prototipo "La Morada"
2023-06-29 Subida de las imágenes en el prototipo real para el recolocador ESP32 DEV KIT V1
2023-06-29 Agregar fotografías reales del recolocador ESP32 para todos los modelos de ATLAS.
2023-06-29 Agregada la inicialización de la VGA64 en el recolocador ESP32.
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2023-06-29 Agregada la información para la incialización de la vga por parte del ESP32
2023-06-29 Agregada información de la inIcialización de los pines VGA64 del recolocador ESP32 en FABGL
2023-06-29 Inicialización de FABGL con el recolocador ESP32 en IO BOARD ATLAS.
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

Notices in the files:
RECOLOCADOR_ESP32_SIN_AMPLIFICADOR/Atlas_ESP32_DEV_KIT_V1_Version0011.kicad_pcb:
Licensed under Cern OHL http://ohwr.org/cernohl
